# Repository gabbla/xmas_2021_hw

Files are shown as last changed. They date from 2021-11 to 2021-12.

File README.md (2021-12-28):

# Xmas 2021

This is the repository that contains the xmas 2021 badge schematic and pcb.
The badge is equipped with an [STM8L101F2P3] MCU, a coin cell, a push button and
7 LEDs. There are various test point so you can play with it, if you want.

A jig programmer adapter is provided in [prog_adapter](prog_adapter). Since a
lot of PCBs were made, the adapter gave an huge help during the programming
phase: no extra pin header or soldering required.



## Hardware

The BoM has been kept as minimal as possible to reduce costs.

| Annotation | Part | Package | Q.ty | Note |
|---|---|---|---|---|
| BT1 | BH57A-5 | | 1 | CR1616/CR1620 battery holder |
| C1, C3 | 100nF | 0603 | 2 | |
| C2 | 10uF | 0603 | 1 | |
| D1 - D7 | LED | 0603 | 7 | Red, Green, Blue, Orange SMD LEDs |
| J1 | 00-9155-004-251-006 | | 0 | Slide contact, receiver footprint only |
| R1, R2 | 4k7 | 0603 | 2 | I2C optional pull-up |
| R3 - R9 | 100 - 150 | 0603 | 7 | LEDs resistor |
| SW1 | PTS526 SK15 SMTR2 LFS | | 1 | User button |
| U1 | STM8L101F2P3 | TSSOP20 | 1 | MCU |

The PCB cutout and top silk screen were traced from a PNG icon (see [credits](#credits) below) using
[svg2shenzhen], an Inkscape plugin. The source image in both PNG and SVG (traced from the PNG) can be found
in [res](res). The [svg2shenzhen] output is a KiCad library.

The resulting PCB:

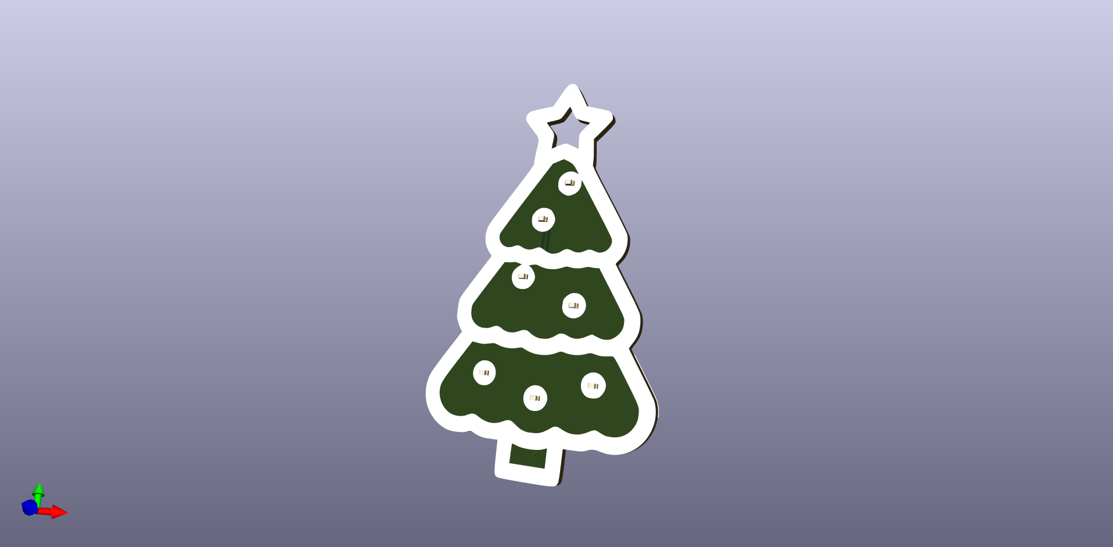
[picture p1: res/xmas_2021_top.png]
top


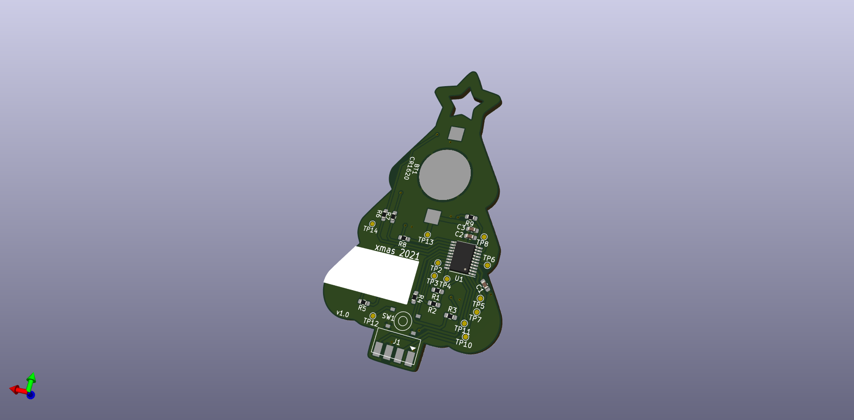
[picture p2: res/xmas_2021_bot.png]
bot


## Firmware

The firmware can be found [here](https://github.com/SebastianoC94/XMAS_Tree_2021). Thanks [@SebastianoC94]!

The firmware can be flashed with any SWIM-capable probe (JLink, STLinkV2/V3).

## Credits

- [@SebastianoC94]
- KiCad
- [svg2shenzhen]
- PCB cutout traced from [this](https://www.flaticon.com/free-icon/christmas-tree_6118946) flaticon image. Artist: [Freepik](https://www.freepik.com)

[STM8L101F2P3]: https://www.st.com/en/microcontrollers-microprocessors/stm8l101f2.html
[svg2shenzhen]: https://github.com/badgeek/svg2shenzhen
[@SebastianoC94]: https://github.com/SebastianoC94

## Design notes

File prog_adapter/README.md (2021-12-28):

# Xmas 2021 prog adapter

This jig is aimed to simplify the programming process on a large number of pieces.
It is possible to flash (and debug) a PCB in the matter of seconds, just slide in
the tree!

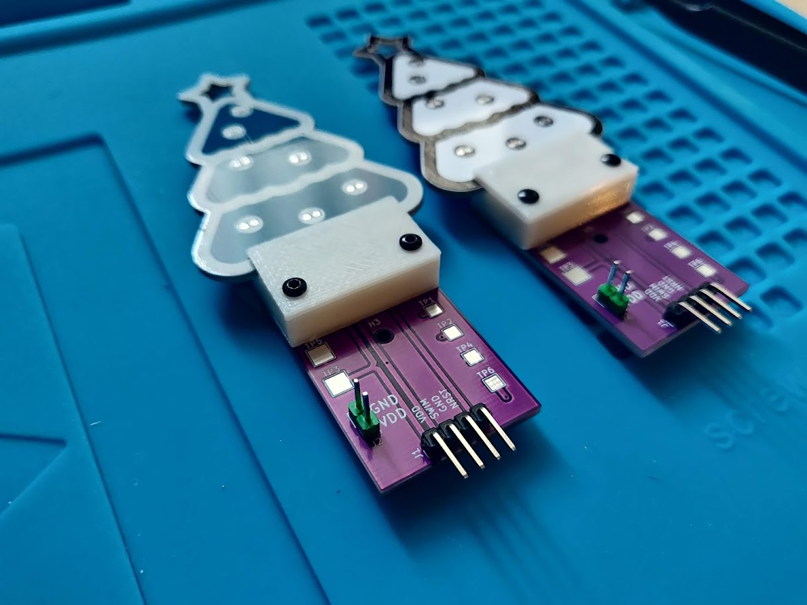
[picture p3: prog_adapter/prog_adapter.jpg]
adapter


The 3D model is relized with [SolveSpace](https://solvespace.com/index.pl).

It is possible to use the voltage reference from the tree battery holder or use
an external PSU through the various header/test points. The programming probe
connects to J1.

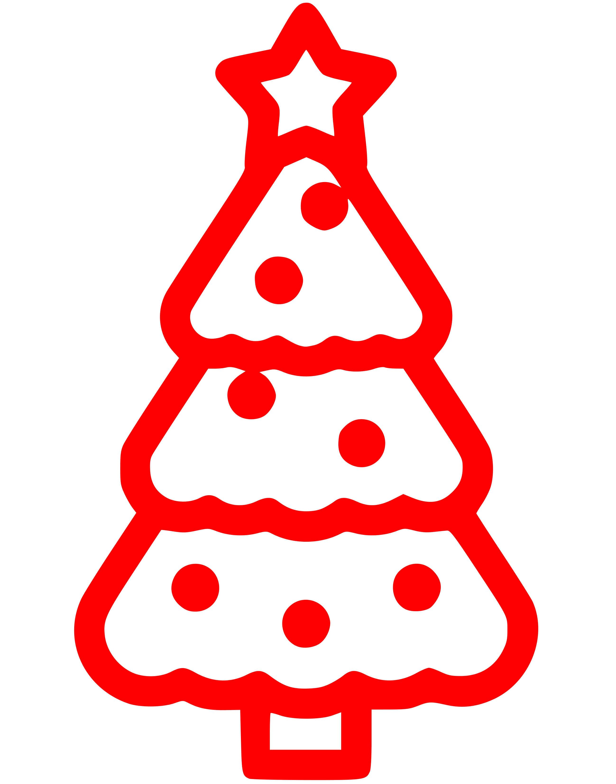
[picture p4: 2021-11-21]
.svg2shenzhen-cache/images/F.SilkS_g21.png

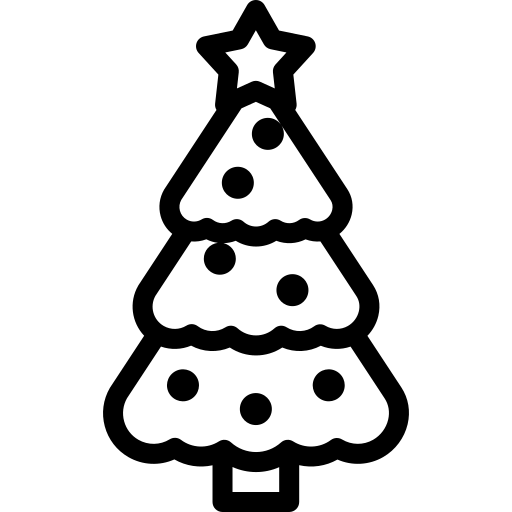
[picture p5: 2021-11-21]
res/christmas-tree.png

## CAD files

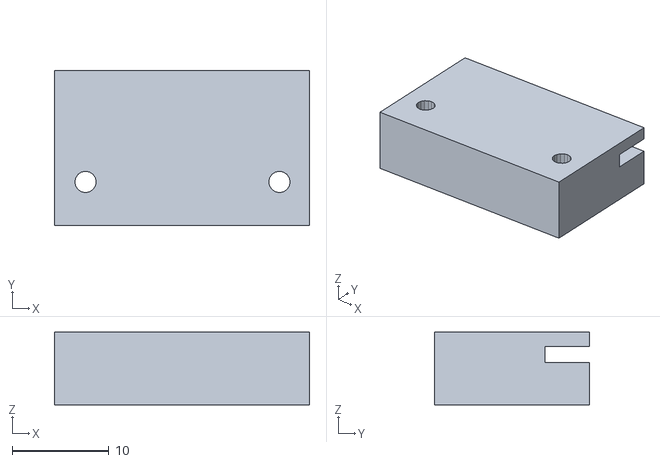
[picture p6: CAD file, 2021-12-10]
prog_adapter/jig_v3.stl
26.3 x 16.0 x 7.50

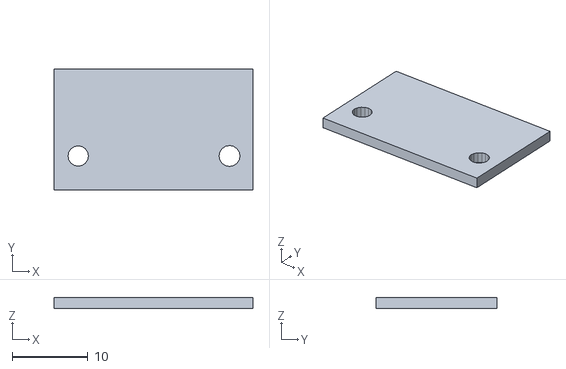
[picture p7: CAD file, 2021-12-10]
prog_adapter/top.stl
26.3 x 16.0 x 1.50

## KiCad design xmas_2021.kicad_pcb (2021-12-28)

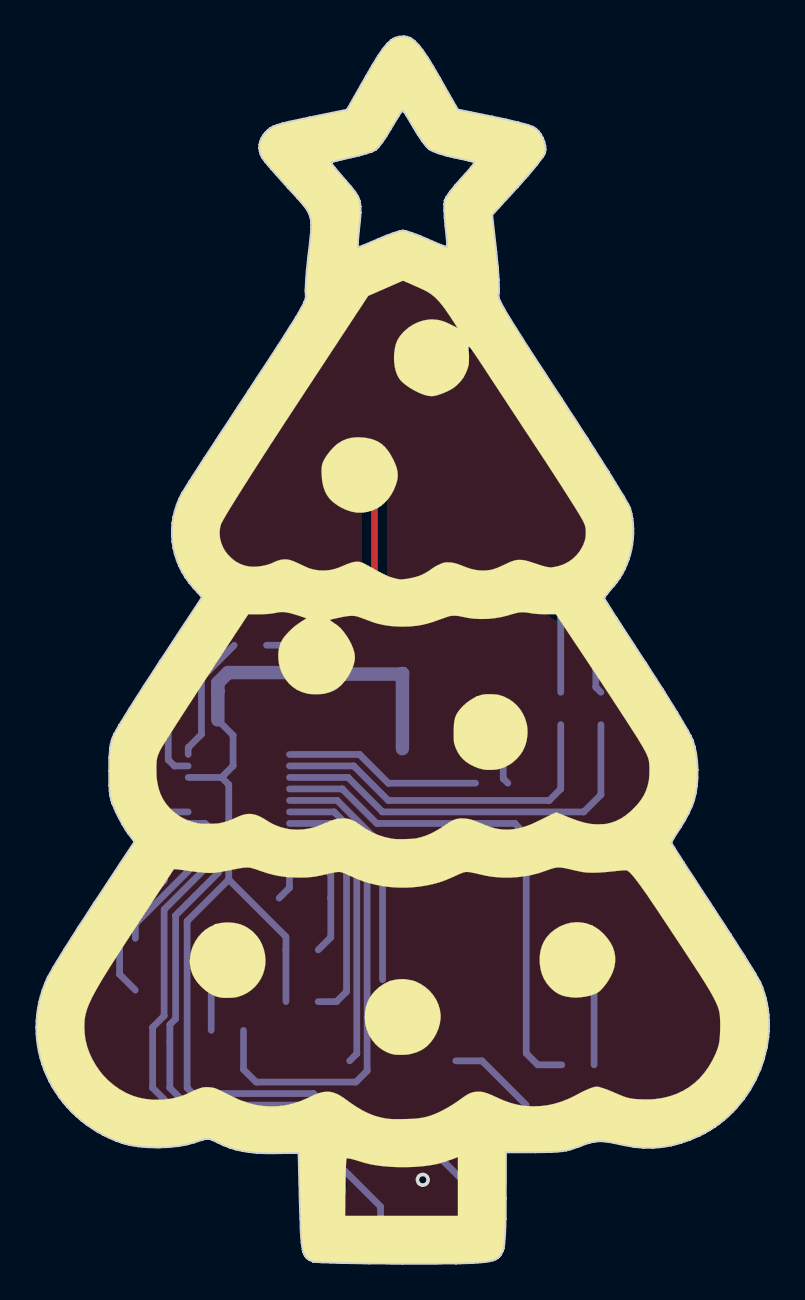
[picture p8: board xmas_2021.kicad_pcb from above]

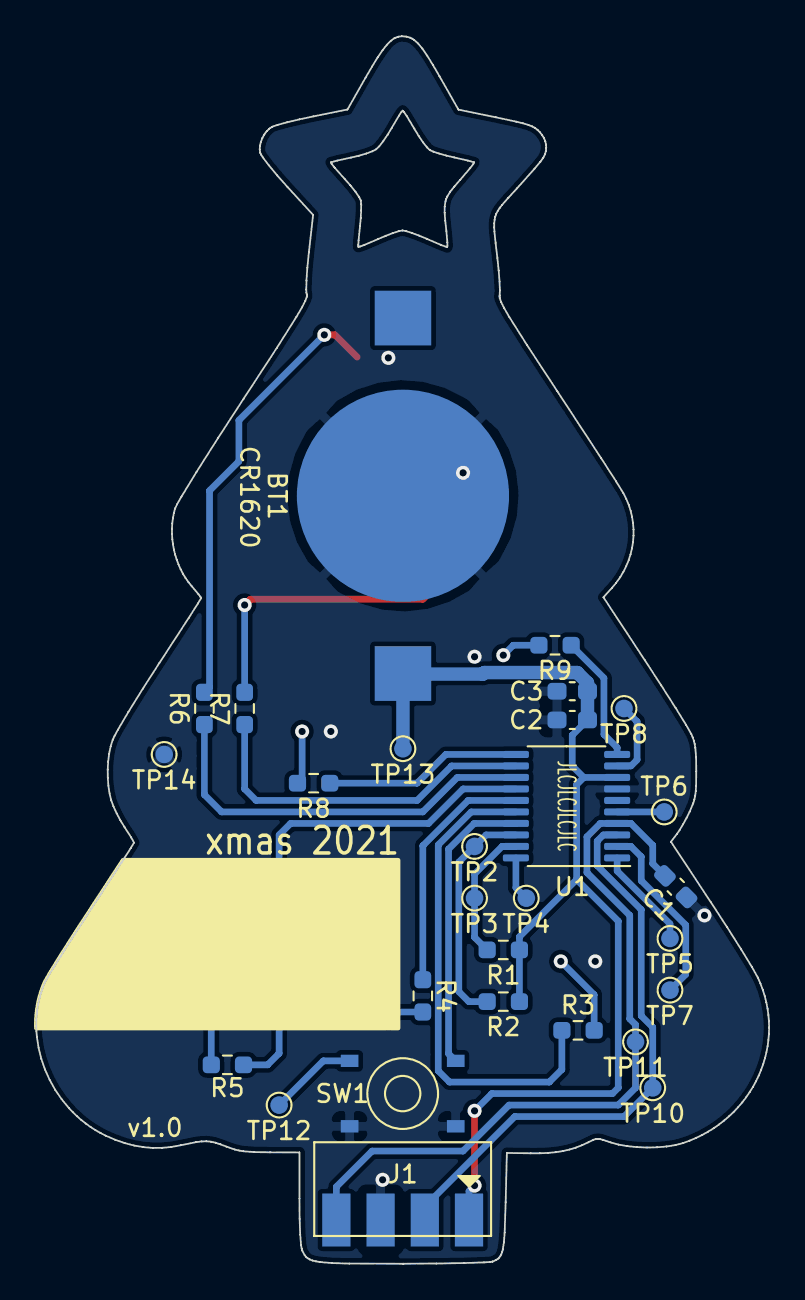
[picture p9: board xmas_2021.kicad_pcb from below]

Board: 2 copper layers, 41.4 x 69.4 mm, 36 parts (28 on the bottom side), 27 nets.

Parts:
BT1: CR2032; BH57A-5
C1, C3: 100n; C_0603_1608Metric_Pad1.08x0.95mm_HandSolder
C2: 10u; C_0603_1608Metric_Pad1.08x0.95mm_HandSolder
D1, D2, D3, D4, D5, D6, D7: LED; LED_0603_1608Metric_Pad1.05x0.95mm_HandSolder
J1: SWIM; swim
R1, R2: DNP; R_0603_1608Metric_Pad0.98x0.95mm_HandSolder
R3, R4, R5, R6, R7, R8, R9: R; R_0603_1608Metric_Pad0.98x0.95mm_HandSolder
Ref**: Val**; christmas-tree
SW1: User; button
TP2: I2C_DATA; TestPoint_Pad_D1.0mm
TP3: I2C_CLOCK; TestPoint_Pad_D1.0mm
TP4: USART_RX; TestPoint_Pad_D1.0mm
TP5: USART_TX; TestPoint_Pad_D1.0mm
TP6: IO1; TestPoint_Pad_D1.0mm
TP7: IO2; TestPoint_Pad_D1.0mm
TP8: IO3; TestPoint_Pad_D1.0mm
TP10: SWIM; TestPoint_Pad_D1.0mm
TP11: NRST; TestPoint_Pad_D1.0mm
TP12: USR_BTN; TestPoint_Pad_D1.0mm
TP13: VBATT; TestPoint_Pad_D1.0mm
TP14: GND; TestPoint_Pad_D1.0mm
U1: STM8L101F2P3; TSSOP-20_4.4x6.5mm_P0.65mm

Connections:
+BATT: BT1.1, C2.1, C3.1, J1.1, R1.1, R2.1, TP13.1, U1.8
/I2C_CLOCK: R1.2, TP3.1, U1.19
/I2C_DATA: R2.2, TP2.1, U1.18
/IO1: TP6.1, U1.5
/IO2: TP7.1, U1.2
/IO3: TP8.1, U1.9
/LED0: R3.1, U1.16
/LED1: R4.1, U1.15
/LED2: R5.1, U1.14
/LED3: R6.1, U1.13
/LED4: R7.1, U1.12
/LED5: R8.1, U1.11
/LED6: R9.1, U1.10
/NRST: C1.1, J1.4, TP11.1, U1.4
/SWIM: J1.2, TP10.1, U1.3
/USART_RX: TP4.1, U1.20
/USART_TX: TP5.1, U1.1
GND: BT1.2, C1.2, C2.2, C3.2, D1.1, D2.1, D3.1, D4.1, D5.1, D6.1, D7.1, J1.3, SW1.1, SW1.2, TP14.1, U1.7
unnamed: D1.2, R3.2
unnamed: D2.2, R4.2
unnamed: D3.2, R5.2
unnamed: D4.2, R6.2
unnamed: D5.2, R7.2
unnamed: D6.2, R8.2
unnamed: D7.2, R9.2
unnamed: SW1.3, U1.17
unnamed: SW1.4, TP12.1

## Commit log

2021-11-18 sch: update after hw test
    [xmas_2021.sch]
2021-11-21 first version
    [xmas_2021.sch]
2021-11-21 pcb: added JLC sn placeholder
    [xmas_2021.kicad_pcb]
2021-11-28 battery holder is now BH57A-5
    [xmas_2021.kicad_pcb, xmas_2021.sch]
2021-11-28 removed unwanted symbols
    [xmas_2021.kicad_pcb]
2021-12-10 prog adapter added
    [jig_v3.stl, top.stl]
2021-12-28 minor fixes
    [xmas_2021.kicad_pcb, xmas_2021.sch]
2021-12-28 kicad pro sync
